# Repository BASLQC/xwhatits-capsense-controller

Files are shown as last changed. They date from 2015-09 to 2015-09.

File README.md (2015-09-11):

## **IBM Capsense USB Controllers**

[Xwhatit at Geekhack](https://geekhack.org/index.php?topic=58192) has developed a set of USB controllers for the IBM capacitive keyboards (Model F and Beamspring). These allow keyboards that otherwise have no way to hook them up to a modern PC to be used (Beamsprings), offer an alternative to Soarer's excellent converter (standard Model Fs), and also an alternative to the other intriguing capsense project around, the DPH controller. It allows the potential to go a bit further than just a converter if you're trying to do something a bit unusual—like build your own keyboard using old Model F bits, add extra keys that the original controller won't support, or get full make/break scancodes with NKRO on a terminal keyboard.

* The BASLQC has archived the GPLv3 source code [on Github in this repository.](http://github.com/baslqc/xwhatits-capsense-controller) Xwhatit wrote the original controller, we're just forking it within the rights of the GPLv3.
* [Schematics/PCBs/precompiled binaries will available at Xwhatit's website for now.](http://downloads.cornall.co/ibm-capsense-usb)

### Features

*  Open source! (GPLv3)
*  Approx. 500Hz scan rate with fast debounce
*  **Full NKRO** (without needing to add diodes—yay capacitive keys) over USB on all Windows/Linux/Mac OS X, while retaining boot-mode compatibility for BIOS etc.
*  Auto-calibration of capsense thresholds
*  Media/consumer keys mappable
*  Layer support with 3 function keys; function keys support chording
*  Macro support
*  Cross-platform (Windows/Linux/Mac OS X) graphical configuration utility to set layout/layers/configure scanning
*  Expansion header on all boards to support LEDs, solenoid drivers (for some Beamsprings), buzzers (on Kishsavers) etc.
*  Compact surface-mount design without needing to plug in external Teensys etc.

## The Controllers

### Beamspring-USB-Rev4
[attach=1]
This supports the standard Beamspring boards, such as the 5251, 3278, 3727 etc., which have a 23x4 matrix. It **will not** work on a Beamspring Displaywriter despite the identical 30-pin connector, as these have a 12x8 matrix—see below for that controller.

This can be paired with the solenoid driver board (see below) for Extra Loud Click, if your Beamspring is fitted with a solenoid (the 3727 is the only one I'm aware of that isn't).

USB connects via an on-board mini-USB socket.

PCB at OSHPark: http://oshpark.com/shared_projects/bOXMsRYH

### Beamspring-Displaywriter-USB-Rev1
[attach=2]
This is to support the unusual Beamspring Displaywriter keyboards, which have a very different 12x8 matrix, with interleaved rows. They will not work with a Model F Displaywriter; as far as I'm aware these have built-in (non-removable) controllers.

USB connects via an on-board mini-USB socket.

PCB at OSHPark: http://oshpark.com/shared_projects/KcxYPs3y

### Model-F-USB-Rev1
[attach=3]

(photo shows Rev1 boards)
Rev2 PCB below (black lines show the actual board cutout):
[img width=640 height=145]http://uploads.oshpark.com/uploads/project/top_image/eTR858GJ/i.png[/img]

This should work with all Model F keyboards (including the Kishsaver) which have separate controllers. Unfortunately this excludes the XT and a couple of other terminal boards, which have a controller-on-board which can't be removed (except maybe with a hacksaw).

Some Model F keyboards have less than 16 columns; columns can be set to `skip' using the GUI util.

These do unfortunately require soldering; IBM used a soldered-on ribbon cable for the Model F controllers, that first needs to be removed from the old controller, then attached to this one.

In the Rev2 board (unlike the Rev1 in the photo below, which has a flying lead), a USB micro (not mini!) is socket is used. This is to reduce board size a bit and these days USB micro sockets are much more common.

PCB at OSHPark: http://oshpark.com/shared_projects/eTR858GJ

## Accessory boards

### Beamspring-USB-Solenoid-Driver-Rev2
[attach=4]
(photo shows prototype, not Rev2)

This is drive the solenoid fitted to most beamspring keyboads. It runs off the USB voltage supply to the main controller, and uses a current-limited switch-mode power supply to boost up to 9V. This is then used to fire the solenoid when a key is pressed for Extra Loud Click coupled with Small Blinking Light.

PCB at OSHPark: http://oshpark.com/shared_projects/qdZwUHLH

### Model-F-3178-Adaptor-Rev1
[img width=640 height=33]http://uploads.oshpark.com/uploads/project/top_image/bD4fQlCX/i.png[/img]
[img width=640 height=33]http://uploads.oshpark.com/uploads/project/bottom_image/bD4fQlCX/i.png[/img]

An adaptor board for IBM 3178 keyboards, which were kind of an unusual Model F version of a 3278/3727 Beamspring. They unfortunately have a different pinout and require this adaptor.

PCB at OSHPark: http://oshpark.com/shared_projects/bD4fQlCX

## GUI Util
[attach=5]
This is a Qt application which runs on Linux, Windows and Mac OS X. Its main purpose is to allow you to set which key location corresponds to which scancode:
[attach=6]
...but also allows tweaking expansion port settings, like whether to run in LED mode for Caps/Num/Scroll Lock indicators, or whether to fire a solenoid (and adjust timings of it etc.).

This also is handy for diagnostic output to show which keys are being sensed as up or down.

## Building your own
Give it a go! Sourcecode/schematics/PCB layouts are here: http://downloads.cornall.co/ibm-capsense-usb . You can order pre-Gerbered PCBs from OSHPark by using the links above, or checking my profile on OSHPark here: http://oshpark.com/profiles/xwhatsit . There are people around (me included) who will help you if you run into issues. Surface-mount is easier than through-hole, it just looks scary!

## Pricing/Availability
As mentioned above, these are open-source. If you have a soldering iron and flux, consider building your own! Don't be put off the surface mount soldering, several people (some with no previous surface-mount experience) have now built their own.

However if you're not into picking up resistors with tweezers, I can build one for you and pre-program and test it first. For this, check out the group buy thread over here: http://geekhack.org/index.php?topic=58192

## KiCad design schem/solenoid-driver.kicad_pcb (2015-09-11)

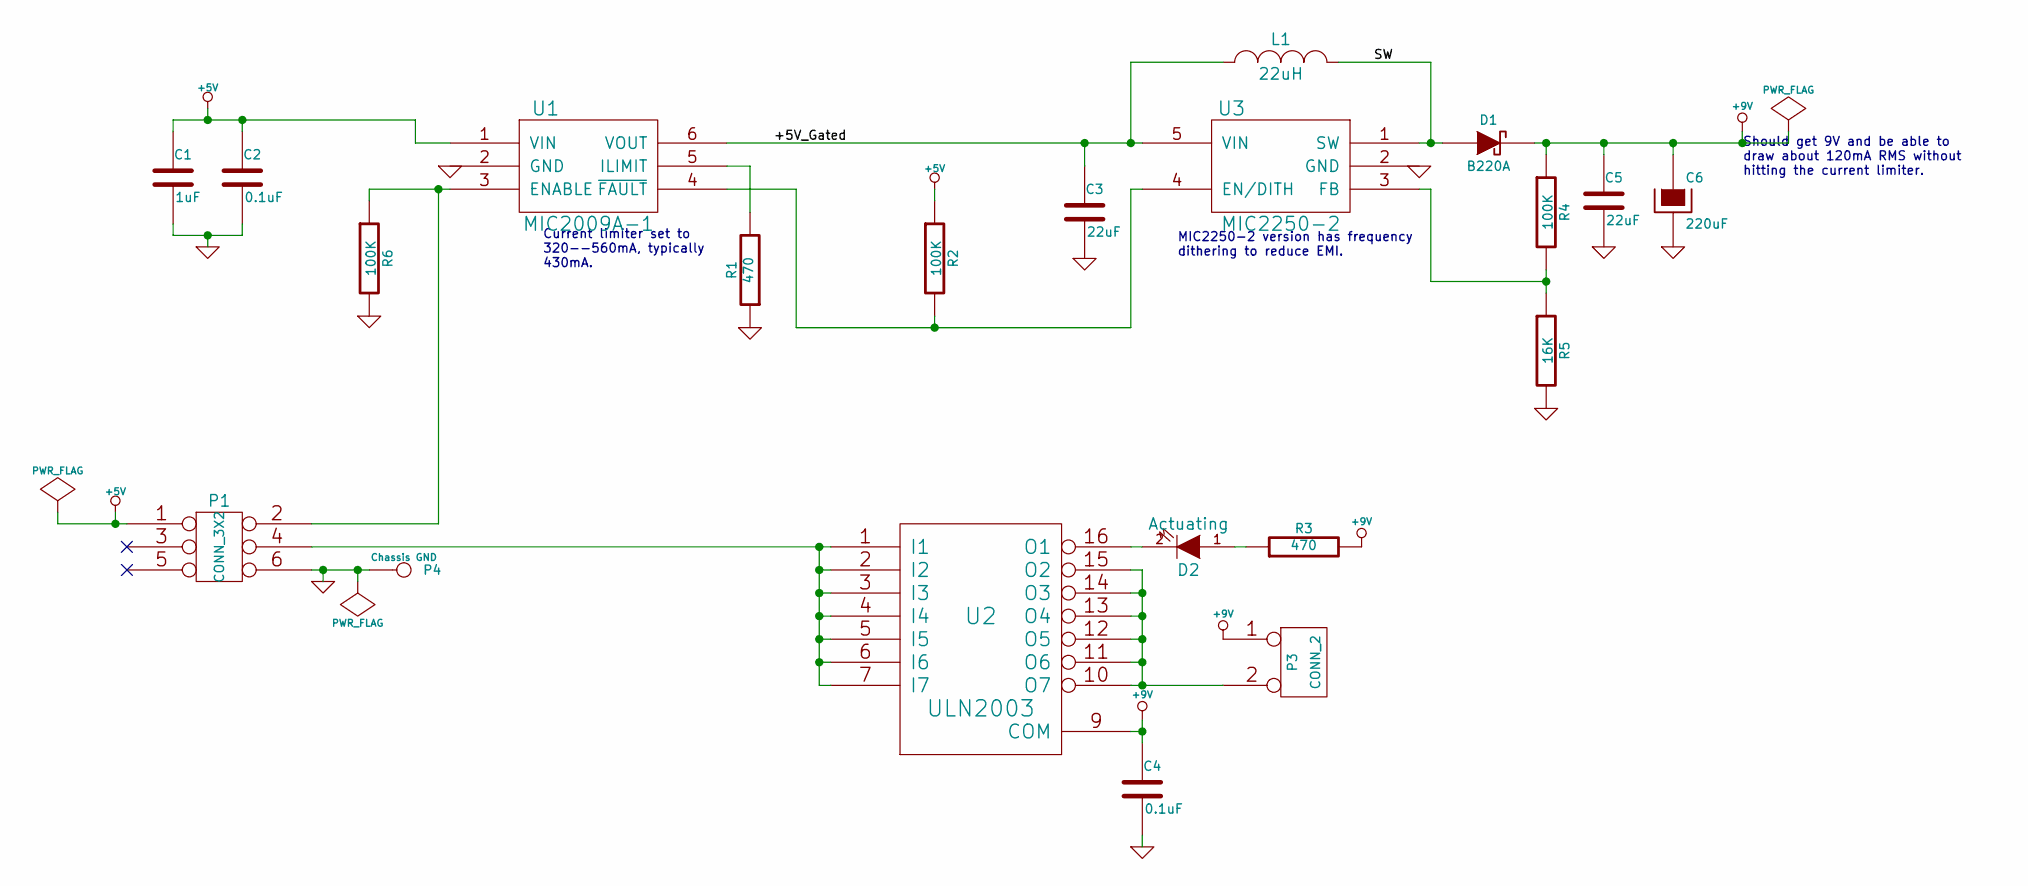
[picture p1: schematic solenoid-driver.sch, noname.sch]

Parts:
C1: 1uF
C2, C4: 0.1uF
C3, C5: 22uF
C6: 220uF
D1: B220A
D2: Actuating
L1: 22uH
P1: CONN_3X2
P3: CONN_2
P4: Chassis GND
R1, R3: 470
R2, R4, R6: 100K
R5: 16K
U1: MIC2009A-1
U2: ULN2003
U3: MIC2250-2

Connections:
+5V: C1.1, C2.1, P1.1, R2.1, U1.1 (VIN)
+9V: C4.1, C5.1, C6.1, D1.2 (K), P3.1, R3.2, R4.1, U2.9 (COM)
/+5V_Gated: C3.1, L1.1, U1.6 (VOUT), U3.5 (VIN)
/SW: D1.1 (A), L1.2, U3.1 (SW)
GND: C1.2, C2.2, C3.2, C4.2, C5.2, C6.2, P1.6, P4.1, R1.1, R5.2, R6.2, U1.2 (GND), U2.8 (GND), U3.2 (GND)
unnamed: R1.2, U1.5 (ILIMIT)
unnamed: P1.4, U2.1 (I1), U2.2 (I2), U2.3 (I3), U2.4 (I4), U2.5 (I5), U2.6 (I6), U2.7 (I7)
unnamed: P3.2 (PM), U2.10 (O7), U2.11 (O6), U2.12 (O5), U2.13 (O4), U2.14 (O3), U2.15 (O2)
unnamed: P1.2, R6.1, U1.3 (ENABLE)
unnamed: D2.2 (K), U2.16 (O1)
unnamed: D2.1 (A), R3.1
unnamed: R2.2, U1.4 (~FAULT), U3.4 (EN/DITH)
unnamed: R4.2, R5.1, U3.3 (FB)

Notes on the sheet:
Should get 9V and be able to draw about 120mA RMS without hitting the current limiter.
Current limiter set to 320--560mA, typically 430mA.
MIC2250-2 version has frequency dithering to reduce EMI.

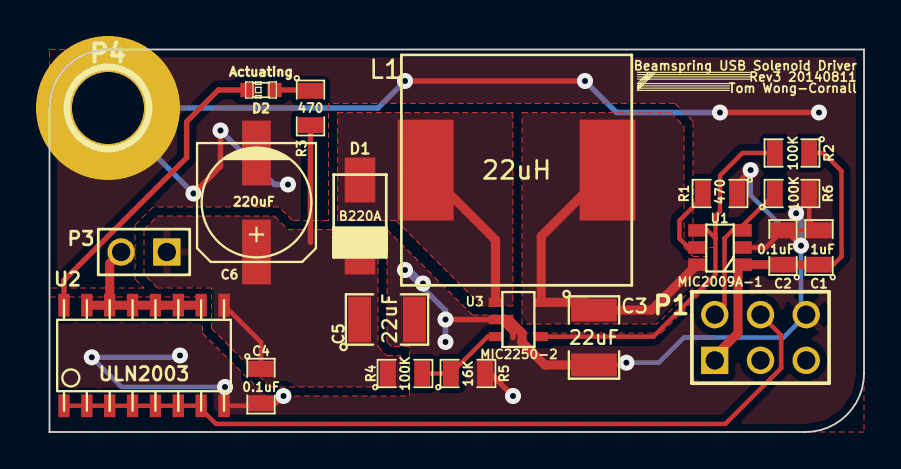
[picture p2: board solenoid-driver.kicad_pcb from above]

Board: 2 copper layers, 45.2 x 21.2 mm, 21 parts (0 on the bottom side), 13 nets.

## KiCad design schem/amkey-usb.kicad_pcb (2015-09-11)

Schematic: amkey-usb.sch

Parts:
C1, C2: 22pF
C3: 4.7uF
C4, C6, C7, C8, C9, C10, C11, C12: 0.1uF
C5: 1uF
P1: USB
P2: CONN_3X2
P3: Columns
P4: Rows
R1, R2: 22
R3, R6: 20K
R4, R7: 4.7K
R5, R9: 10K
R8: 1K
RP1, RP2: 10K
RP3, RP4: 100K
SW1: PROG
SW2: RESET
U1: ATMEGA32U2
U2: DAC101S101; MODULE
U3, U4: LM339A
U5, U6: 74AHC595
X1: 16MHz

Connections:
/SPI_MOSI: U1.16, U2.4 (DIN)
/SPI_SCLK: U1.15, U2.5 (SCLK)
/SPI_SS: U1.14, U2.6 (SYNC)
/USB_D+: P1.3 (D+), R2.1
/USB_D-: P1.2 (D-), R1.1
/USB_SHIELD: C6.1, P1.6 (SHELL1)
Col1: P3.1, U5.15 (QA)
Col2: P3.3, U5.1 (QB)
Col3: P3.5, U5.2 (QC)
Col4: P3.7, U5.3 (QD)
Col5: P3.9, U5.4 (QE)
Col6: P3.11, U5.5 (QF)
Col7: P3.13, U5.6 (QG)
Col8: P3.15, U5.7 (QH)
Col9: P3.17, U6.15 (QA)
Col10: P3.19, U6.1 (QB)
Col11: P3.21, U6.2 (QC)
Col12: P3.23, U6.3 (QD)
Col13: P3.25, U6.4 (QE)
Col14: P3.27, U6.5 (QF)
Col15: P3.29, U6.6 (QG)
Col16: P3.31, U6.7 (QH)
GND: C1.1, C2.1, C3.2, C4.1, C5.2, C6.2, C7.2, C8.2, C9.1, C10.1, C11.2, C12.2, P1.5 (GND), P2.6, P3.2, P3.4, P3.6, P3.8, P3.10, P3.12, P3.14, P3.16, P3.18, P3.20, P3.22, P3.24, P3.26, P3.28, P3.30, P3.32, P4.2, P4.4, P4.6, P4.8, P4.10, P4.12, P4.14, P4.16, R4.2, R8.2, SW1.1, SW2.2, U1.3, U1.28, U2.2 (GND), U3.12 (GND), U4.12 (GND), U5.8 (GND), U6.8 (GND); also elsewhere on the board
unnamed: R2.2, U1.29
unnamed: R1.2, U1.30
unnamed: C5.1, U1.27
unnamed: C2.2, U1.1, X1.2
unnamed: R3.1, R4.1, R6.2, U3.4 (-), U3.6 (-), U3.8 (-), U3.10 (-), U4.4 (-), U4.6 (-), U4.8 (-), U4.10 (-)
unnamed: C8.1, R5.2, SW2.1, U1.24
unnamed: P2.4, U1.20
unnamed: P2.5, U1.19
unnamed: P2.3, U1.18
unnamed: P2.2, U1.21
unnamed: U5.9 (~QH), U6.14 (SER)
unnamed: R6.1, U2.1 (VOUT)
unnamed: R7.2, R8.1, RP3.1, RP3.2, RP3.3, RP3.4, RP4.1, RP4.2, RP4.3, RP4.4
unnamed: C1.2, U1.2, X1.1
Row1: P4.1, RP3.5 (R4), U3.11 (+)
Row2: P4.3, RP3.6 (R3), U3.9 (+)
Row3: P4.5, RP3.7 (R2), U3.7 (+)
Row4: P4.7, RP3.8 (R1), U3.5 (+)
Row5: P4.9, RP4.5 (R4), U4.11 (+)
Row6: P4.11, RP4.6 (R3), U4.9 (+)
Row7: P4.13, RP4.7 (R2), U4.7 (+)
Row8: P4.15, RP4.8 (R1), U4.5 (+)
RowOP1: RP1.4, U1.26, U3.13
RowOP2: RP1.3, U1.25, U3.14
RowOP3: RP1.2, U1.23, U3.1
RowOP4: RP1.1, U1.22, U3.2
RowOP5: RP2.4, U1.6, U4.13
RowOP6: RP2.3, U1.7, U4.14
RowOP7: RP2.2, U1.8, U4.1
RowOP8: RP2.1, U1.9, U4.2
SR_DS: U1.10, U5.14 (SER)
SR_OE: U1.11, U5.13 (G), U6.13 (G)
SR_SHCP: R9.2, SW1.2, U1.13, U5.11 (SRCLK), U6.11 (SRCLK)
SR_STCP: U1.12, U5.12 (RCLK), U6.12 (RCLK)
VCC: C3.1, C4.2, C7.1, C9.2, C10.2, C11.1, C12.1, P1.1 (VBUS), P2.1, R3.2, R5.1, R7.1, R9.1, RP1.5 (R4), RP1.6 (R3), RP1.7 (R2), RP1.8 (R1), RP2.5 (R4), RP2.6 (R3), RP2.7 (R2), RP2.8 (R1), U1.4, U1.31, U1.32, U2.3 (VA), U3.3 (V+), U4.3 (V+), U5.10 (SRCLR), U5.16 (VCC), U6.10 (SRCLR), U6.16 (VCC)

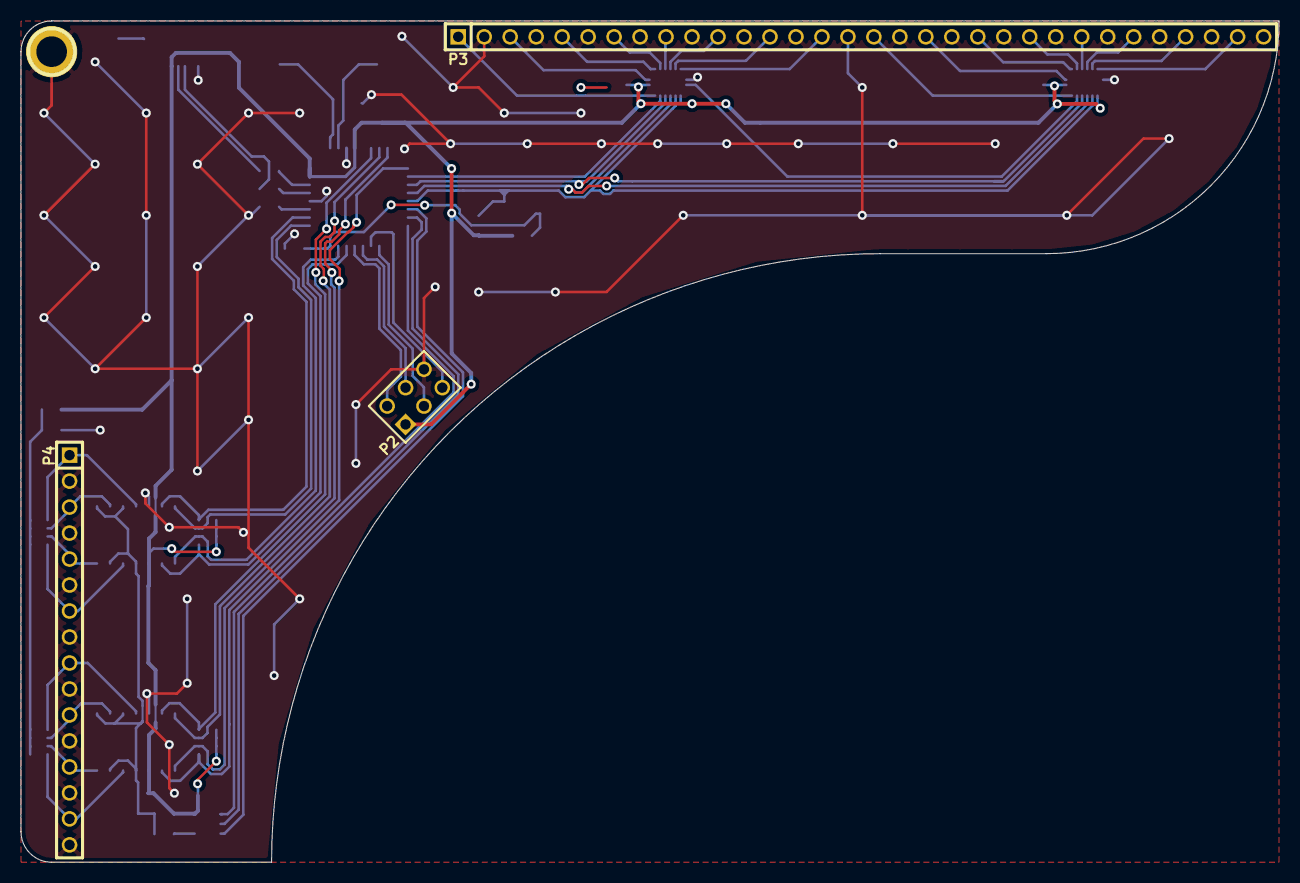
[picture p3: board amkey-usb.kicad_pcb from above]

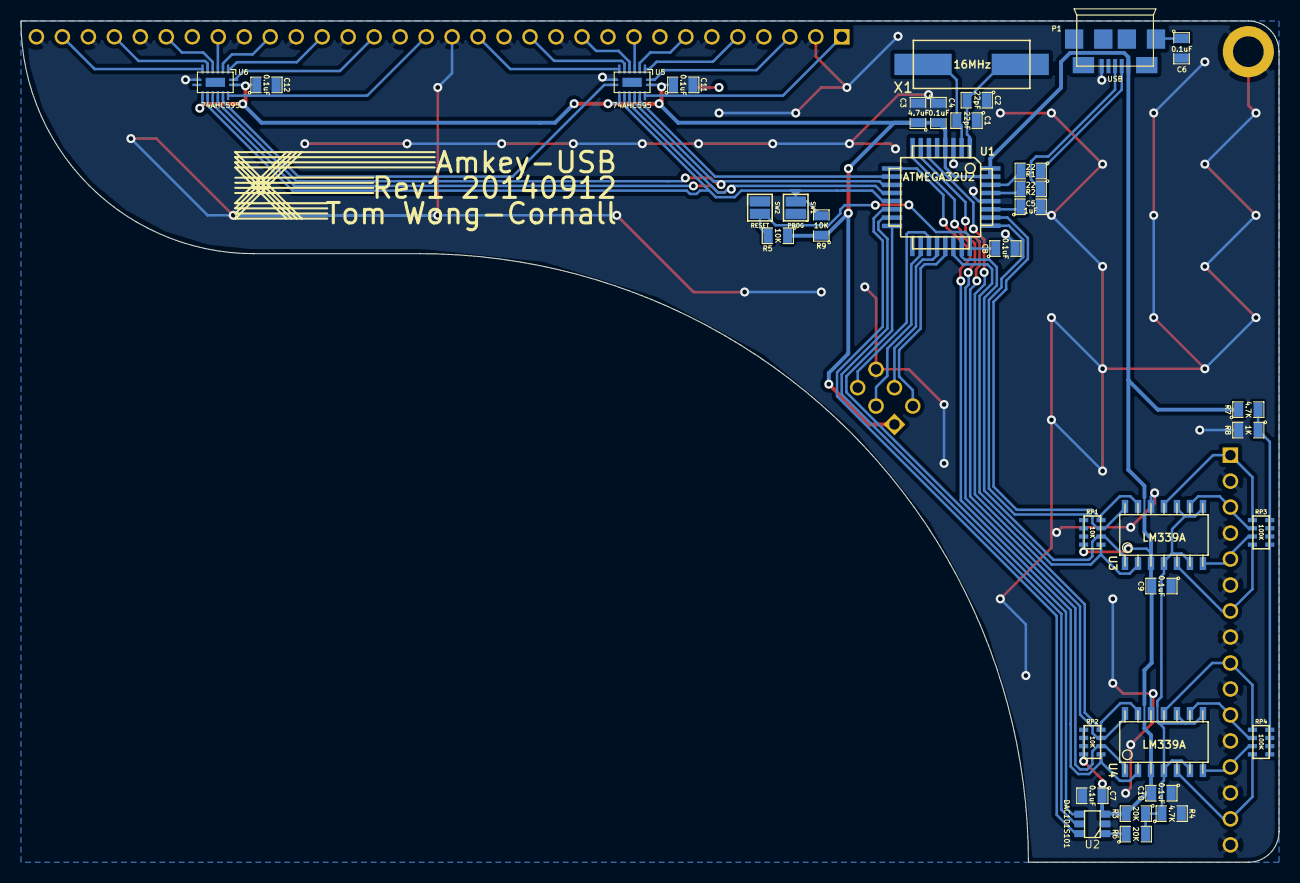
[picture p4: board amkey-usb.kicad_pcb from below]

Board: 2 copper layers, 123.0 x 82.2 mm, 39 parts (35 on the bottom side), 58 nets.

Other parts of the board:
1PIN: P***; 1pin

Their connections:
GND: 1PIN.1; also elsewhere on the board

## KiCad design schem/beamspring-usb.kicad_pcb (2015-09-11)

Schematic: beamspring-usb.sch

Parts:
C1: 1uF
C2, C6, C7, C8, C9, C10, C11, C12: 0.1uF
C3, C4: 22pF
C5: 4.7uF
CON1: USB-MINI-B
P1: EDGE_30X2; MODULE
P2: CONN_3X2
R1, R2, R16: 10K
R3, R17: 20K
R4: 4.7K
R5, R6: 22
R15: 47K
RP1: 10K
RP2: 100K
SW1, SW2: SW_PUSH
U1: ATMEGA32U2
U2: DAC101S101; MODULE
U3, U4, U5: 74AHC595
U6: LM339
X1: 16MHz

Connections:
/SR_DS: U1.26, U3.14 (SER)
/SR_OE: U1.23, U3.13 (G), U4.13 (G), U5.13 (G)
/SR_SHCP: U1.25, U3.11 (SRCLK), U4.11 (SRCLK), U5.11 (SRCLK)
/SR_STCP: U1.22, U3.12 (RCLK), U4.12 (RCLK), U5.12 (RCLK)
GND: C1.2, C2.2, C3.1, C4.1, C5.2, C6.1, C7.2, C8.2, C9.2, C10.2, C11.2, C12.2, CON1.5 (GND), P1.1, P1.26, P1.31, P1.56, P2.6, R4.2, R16.2, SW1.1, SW2.2, U1.3, U1.28, U2.2 (GND), U3.8 (GND), U4.8 (GND), U5.8 (GND), U6.12 (GND); also elsewhere on the board
unnamed: R15.2, R16.1, RP2.1, RP2.2, RP2.3, RP2.4
unnamed: U1.16, U2.4 (DIN)
unnamed: U1.14, U2.6 (SYNC)
unnamed: U1.15, U2.5 (SCLK)
unnamed: R17.1, U2.1 (VOUT)
unnamed: U4.9 (~QH), U5.14 (SER)
unnamed: C4.2, U1.1, X1.2
unnamed: CON1.2 (D-), R5.1
unnamed: C7.1, CON1.7 (SHELL2)
unnamed: R5.2, U1.30
unnamed: R6.2, U1.29
unnamed: CON1.3 (D+), R6.1
unnamed: C2.1, R2.2, SW2.1, U1.24
unnamed: C1.1, U1.27
unnamed: R1.2, SW1.2, U1.13
unnamed: R3.1, R4.1, R17.2, U6.4 (-), U6.6 (-), U6.8 (-), U6.10 (-)
unnamed: RP1.1, U1.6, U6.2
unnamed: RP1.2, U1.7, U6.1
unnamed: P2.2, U1.21
unnamed: RP1.3, U1.9, U6.14
unnamed: RP1.4, U1.8, U6.13
unnamed: P2.3, U1.18
unnamed: P2.5, U1.19
unnamed: P2.4, U1.20
unnamed: U3.9 (~QH), U4.14 (SER)
unnamed: P1.7, P1.37, U3.5 (QF)
unnamed: P1.2, P1.32, U3.15 (QA)
unnamed: P1.3, P1.33, U3.1 (QB)
unnamed: P1.4, P1.34, U3.2 (QC)
unnamed: P1.5, P1.35, U3.3 (QD)
unnamed: P1.6, P1.36, U3.4 (QE)
unnamed: P1.8, P1.38, U3.6 (QG)
unnamed: P1.9, P1.39, U3.7 (QH)
unnamed: P1.10, P1.40, U4.15 (QA)
unnamed: P1.20, P1.50, U5.1 (QB)
unnamed: P1.30, P1.60, RP2.8 (R1), U6.9 (+)
unnamed: P1.11, P1.41, U4.1 (QB)
unnamed: P1.21, P1.51, U5.2 (QC)
unnamed: P1.18, P1.48, U4.7 (QH)
unnamed: P1.17, P1.47, U4.6 (QG)
unnamed: P1.27, P1.57, RP2.5 (R4), U6.5 (+)
unnamed: P1.28, P1.58, RP2.7 (R2), U6.7 (+)
unnamed: P1.19, P1.49, U5.15 (QA)
unnamed: P1.29, P1.59, RP2.6 (R3), U6.11 (+)
unnamed: P1.12, P1.42, U4.2 (QC)
unnamed: P1.22, P1.52, U5.3 (QD)
unnamed: P1.13, P1.43, U4.3 (QD)
unnamed: P1.23, P1.53, U5.4 (QE)
unnamed: P1.14, P1.44, U4.4 (QE)
unnamed: P1.24, P1.54, U5.5 (QF)
unnamed: P1.15, P1.45, U4.5 (QF)
unnamed: P1.25, P1.55, U5.6 (QG)
unnamed: C3.2, U1.2, X1.1
VCC: C5.1, C6.2, C8.1, C9.1, C10.1, C11.1, C12.1, CON1.1 (VBUS), P2.1, R1.1, R2.1, R3.2, R15.1, RP1.5 (R4), RP1.6 (R3), RP1.7 (R2), RP1.8 (R1), U1.4, U1.31, U1.32, U2.3 (VA), U3.10 (SRCLR), U3.16 (VCC), U4.10 (SRCLR), U4.16 (VCC), U5.10 (SRCLR), U5.16 (VCC), U6.3 (V+)

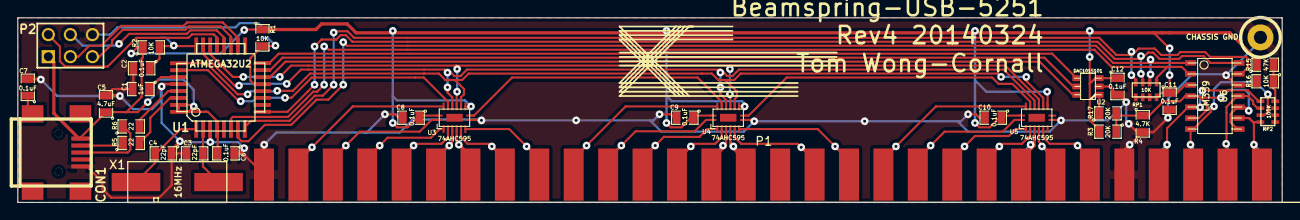
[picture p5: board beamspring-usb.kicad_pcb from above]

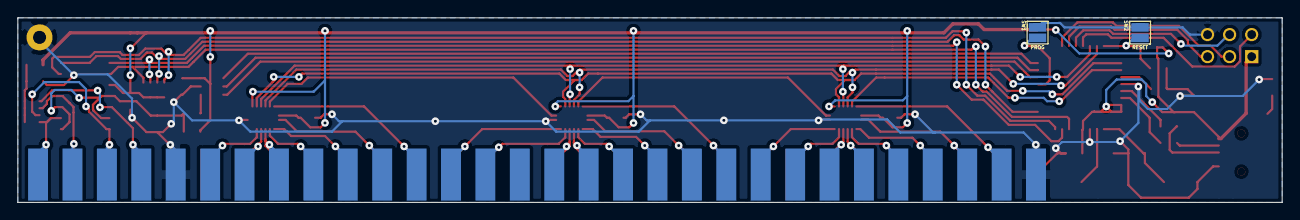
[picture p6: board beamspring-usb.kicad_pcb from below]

Board: 2 copper layers, 145.5 x 21.2 mm, 36 parts (2 on the bottom side), 59 nets.

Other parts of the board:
CHASSIS GND: P***; 1pin

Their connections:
GND: CHASSIS GND.1; also elsewhere on the board

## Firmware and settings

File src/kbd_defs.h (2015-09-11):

/******************************************************************************
  Copyright 2014 Tom Wong-Cornall

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
  You should have received a copy of the GNU General Public License
  along with this program.  If not, see <http://www.gnu.org/licenses/>.  
 ******************************************************************************/
#ifndef KBD_DEFS_H
#define KBD_DEFS_H

#if defined(BEAMSPRING)
#	define KBD_COLS 23
#	define KBD_ROWS 4
#	if BOARD_REV <= 2
#		define KBD_ROW1_PIN PINB
#		define KBD_ROW2_PIN PINB
#		define KBD_ROW3_PIN PINB
#		define KBD_ROW4_PIN PINB
#		define KBD_ROW1_IP  PB0
#		define KBD_ROW2_IP  PB1
#		define KBD_ROW3_IP  PB2
#		define KBD_ROW4_IP  PB3
#	elif BOARD_REV <= 4
#		define KBD_ROW1_PIN PIND
#		define KBD_ROW2_PIN PIND
#		define KBD_ROW3_PIN PIND
#		define KBD_ROW4_PIN PIND
#		define KBD_ROW1_IP  PD0
#		define KBD_ROW2_IP  PD1
#		define KBD_ROW3_IP  PD2
#		define KBD_ROW4_IP  PD3
#	else
#		error "BOARD_REV not understood"
#	endif
#elif defined(MODEL_F)
#	define KBD_COLS     16
#	define KBD_ROWS     8
#	define KBD_ROW1_PIN PIND
#	define KBD_ROW2_PIN PIND
#	define KBD_ROW3_PIN PIND
#	define KBD_ROW4_PIN PIND
#	define KBD_ROW5_PIN PINC
#	define KBD_ROW6_PIN PINC
#	define KBD_ROW7_PIN PINC
#	define KBD_ROW8_PIN PINC
#	define KBD_ROW1_IP  PD3
#	define KBD_ROW2_IP  PD2
#	define KBD_ROW3_IP  PD1
#	define KBD_ROW4_IP  PD0
#	define KBD_ROW5_IP  PC7
#	define KBD_ROW6_IP  PC6
#	define KBD_ROW7_IP  PC5
#	define KBD_ROW8_IP  PC4
#elif defined(BEAMSPRING_DISPLAYWRITER)
#	define KBD_COLS     12
#	define KBD_ROWS     8
#	define KBD_ROW1_PIN PINC
#	define KBD_ROW2_PIN PIND
#	define KBD_ROW3_PIN PINC
#	define KBD_ROW4_PIN PIND
#	define KBD_ROW5_PIN PINC
#	define KBD_ROW6_PIN PIND
#	define KBD_ROW7_PIN PINC
#	define KBD_ROW8_PIN PIND
#	define KBD_ROW1_IP  PC7
#	define KBD_ROW2_IP  PD0
#	define KBD_ROW3_IP  PC6
#	define KBD_ROW4_IP  PD1
#	define KBD_ROW5_IP  PC5
#	define KBD_ROW6_IP  PD2
#	define KBD_ROW7_IP  PC4
#	define KBD_ROW8_IP  PD3
#else
#	error "BOARD_TYPE not specified in makefile"
#endif

#if defined(KEY_POLARITY_AUTO)
#	if defined(BEAMSPRING) || defined(BEAMSPRING_DISPLAYWRITER)
#		define KBD_ACTIVE_LOW
#	elif defined(MODEL_F)
#		define KBD_ACTIVE_HIGH
#	endif
#elif defined(KEY_POLARITY_ACTIVE_HIGH)
#	define KBD_ACTIVE_HIGH
#elif defined(KEY_POLARITY_ACTIVE_LOW)
#	define KBD_ACTIVE_LOW
#else
#	error "KEY_POLARITY not specified in makefile"
#endif

#define KBD_SC_IGNORED       0x00
#define KBD_SC_CAL_HI        0x01
#define KBD_SC_CAL_LO        0x02
#define KBD_SC_EXP_TOGGLE    0x03
#define KBD_SC_SYSTEM_POWER  0xA5
#define KBD_SC_MEDIA_PLAY    0xA8
#define KBD_SC_WEB_BOOKMARKS 0xBD
#define KBD_SC_FN1           0xD0
#define KBD_SC_FN2           0xD1
#define KBD_SC_FN3           0xD2
#define KBD_SC_SELECT_0      0xD8
#define KBD_SC_SELECT_1      0xD9
#define KBD_SC_SELECT_2      0xDA
#define KBD_SC_SELECT_3      0xDB

#endif

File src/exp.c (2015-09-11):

/******************************************************************************
  Copyright 2014 Tom Wong-Cornall

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
  You should have received a copy of the GNU General Public License
  along with this program.  If not, see <http://www.gnu.org/licenses/>.  
 ******************************************************************************/
#include "exp.h"

static uint8_t msCtr;
static uint8_t solenoidQueue;

uint8_t expMode;
uint8_t expVal1; // meaning of val 1 & 2 is depending on mode
uint8_t expVal2;

/*
 *
 */
void
expClear(void)
{
	DDRB  &= ~(1 << PB4);
	DDRB  &= ~(1 << PB5);
	DDRB  &= ~(1 << PB6);
	DDRB  &= ~(1 << PB7);
	PORTB &= ~(1 << PB4);
	PORTB &= ~(1 << PB5);
	PORTB &= ~(1 << PB6);
	PORTB &= ~(1 << PB7);

	msCtr = 0;
	solenoidQueue = 0;

	/* LEDs on the PC-AT seem to have pull-ups; so re-enable outputs so
	 * that the LEDs don't stay on and waste power when this function is
	 * called before USB suspend.
	 */
	if (expMode == expModeLockLEDs) {
		DDRB  |= (1 << PB4);
		DDRB  |= (1 << PB5);
		DDRB  |= (1 << PB6);
	}
}

/*
 *
 */
void
expReset(void)
{
	expClear();

	switch (expMode) {
	case expModeSolenoidPlusNOCapsLockSwitch:
	case expModeSolenoidPlusNCCapsLockSwitch:
	case expModeSolenoidPlusNONumLockSwitch:
	case expModeSolenoidPlusNCNumLockSwitch:
	case expModeSolenoidPlusNOShiftLockSwitch:
	case expModeSolenoidPlusNCShiftLockSwitch:
	case expModeSolenoidPlusNOFn1LockSwitch:
	case expModeSolenoidPlusNCFn1LockSwitch:
	case expModeSolenoidPlusNOFn2LockSwitch:
	case expModeSolenoidPlusNCFn2LockSwitch:
	case expModeSolenoidPlusNOFn3LockSwitch:
	case expModeSolenoidPlusNCFn3LockSwitch:
		PORTB |= (1 << PB5); // turn on pullup for input pin
	case expModeSolenoid:
		DDRB  |= (1 << PB6);
		DDRB  |= (1 << PB7);
		PORTB |= (1 << PB7); // enable 9V SMPS
		break;
	case expModeLockLEDs:
		/* pins will already be set to outputs in expClear() */
		break;
	default:
		break;
	}
}

/*
 *
 */
void
expMSTick(void)
{
	if (msCtr < 0xff)
		msCtr++;

	switch (expMode) {
	case expModeSolenoid:
	case expModeSolenoidPlusNOCapsLockSwitch:
	case expModeSolenoidPlusNCCapsLockSwitch:
	case expModeSolenoidPlusNONumLockSwitch:
	case expModeSolenoidPlusNCNumLockSwitch:
	case expModeSolenoidPlusNOShiftLockSwitch:
	case expModeSolenoidPlusNCShiftLockSwitch:
	case expModeSolenoidPlusNOFn1LockSwitch:
	case expModeSolenoidPlusNCFn1LockSwitch:
	case expModeSolenoidPlusNOFn2LockSwitch:
	case expModeSolenoidPlusNCFn2LockSwitch:
	case expModeSolenoidPlusNOFn3LockSwitch:
	case expModeSolenoidPlusNCFn3LockSwitch:
		if (msCtr == expVal1)
			PORTB &= ~(1 << PB6); // turn off solenoid
		else if (msCtr == expVal2)
			scanResume();
		else if (solenoidQueue > 0 && msCtr > expVal2) {
			msCtr = 0;
			solenoidQueue--;
			PORTB |= (1 << PB6);  // turn on solenoid
			scanPause();
		}
		break;
	default:
		break;
	}
}

/*
 *
 */
static void
loadMode(void)
{
	expMode = eeprom_read_byte((uint8_t *)EEP_EXP_MODE);
	if (expMode >= expModeEND)
		expMode = expModeDisabled;
}

/*
 *
 */
static void
handleFnLockSelect(bool switchState, uint8_t layer)
{
	if (switchState)
		layersDefaultLayer = layer;
	else
		layersDefaultLayer = 0;
}

/*
 *
 */
static void
handleShiftLockSelect(bool switchState)
{
	if (switchState)
		kbdSCBmp[HID_KEYBOARD_SC_LEFT_SHIFT / 8] |=
		   (1 << (HID_KEYBOARD_SC_LEFT_SHIFT % 8));
}

/*
 * This is a bit hard, as we need to look at what the OS is telling us via the
 * keyboard lock LED report, and toggle the corresponding lock key to make it
 * switch state. There's a bit of a lag between getting the new LED states too,
 * so use a counter to have a bit of a timeout before trying again.
 */
static bool
handleLEDKeyLockSelect(bool switchState, uint8_t ledMask, uint8_t scancode)
{
	static uint8_t timeout;

	/* don't do anything if we don't need to */
	if ((!switchState && !(kbdLEDs & ledMask)) ||
	    ( switchState &&  (kbdLEDs & ledMask))) {
		timeout = 0;
		return false;
	}

	if (timeout++ == 0) {
		kbdSCBmp[scancode / 8] |=  (1 << (scancode % 8));
		return true;
	}

	return false;
}

/*
 * look for new keypress edges; ignore the first four scancodes
 * (ignored/pressed/released etc.) and the last chunk which is fn keys and
 * mods.
 */
static void
processSolenoidScancodes(void)
{
	for (uint8_t i = 0; i < KBD_SC_FN1 / 8; i++) {
		uint8_t prev = kbdPrevSCBmp[i];
		uint8_t curr = kbdSCBmp[i];

		if (prev == curr)
			continue;

		/* mask to get new bits from prev -> curr */
		curr = ((prev ^ curr) & ~prev);

		if (i == 0)
			curr &= 0xf0; // get rid of first four scancodes

		/* whack the solenoid once for each set bit */
		while (curr) {
			curr &= (curr - 1);
			solenoidQueue++;
		}
	}
}

/*
 *
 */
static void
setLockLEDs(void)
{
	if (kbdLEDs & HID_KEYBOARD_LED_NUMLOCK)
		PORTB |=  (1 << PB5);
	else
		PORTB &= ~(1 << PB5);

	if (kbdLEDs & HID_KEYBOARD_LED_CAPSLOCK)
		PORTB |=  (1 << PB6);
	else
		PORTB &= ~(1 << PB6);

	if (kbdLEDs & HID_KEYBOARD_LED_SCROLLLOCK)
		PORTB |=  (1 << PB4);
	else
		PORTB &= ~(1 << PB4);
}

/*
 *
 */
static bool
switchIsSet(void)
{
	return !(PINB & (1 << PB5));
}

/*
 * when key-down change-of-state on Exp Toggle key, either load exp mode
 * from EEPROM if currently disabled, or set it to disabled
 */
static void
handleToggleKey(void)
{
	if ( kbdSCIsIn(KBD_SC_EXP_TOGGLE, kbdSCBmp) &&
	    !kbdSCIsIn(KBD_SC_EXP_TOGGLE, kbdPrevSCBmp)) {
		if (expMode == expModeDisabled) {
			loadMode();
			expReset();
		} else {
			expMode = expModeDisabled;
			expClear();
		}
	}
}
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

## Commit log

2015-09-11 initial commit, 0.6.1
    [beamspring-usb.kicad_pcb, beamspring-usb.sch, displaywriter-usb.kicad_pcb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]
2015-09-11 0.6.7, imported from xwhatit's untracked source code
    [model-f-usb.kicad_pcb, model-f-usb.sch]
2015-09-11 0.7.0, imported from xwhatits untracked repository
    [model-f-3178-adaptor.kicad_pcb]
2015-09-11 0.8.0, imported from xwhatits untracked repository
    [amkey-usb.kicad_pcb, amkey-usb.sch, solenoid-driver.kicad_pcb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]

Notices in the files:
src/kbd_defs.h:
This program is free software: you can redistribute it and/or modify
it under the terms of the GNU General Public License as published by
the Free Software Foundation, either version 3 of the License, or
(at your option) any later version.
